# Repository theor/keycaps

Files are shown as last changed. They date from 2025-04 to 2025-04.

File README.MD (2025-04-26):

# Openscad labeled choc keycaps

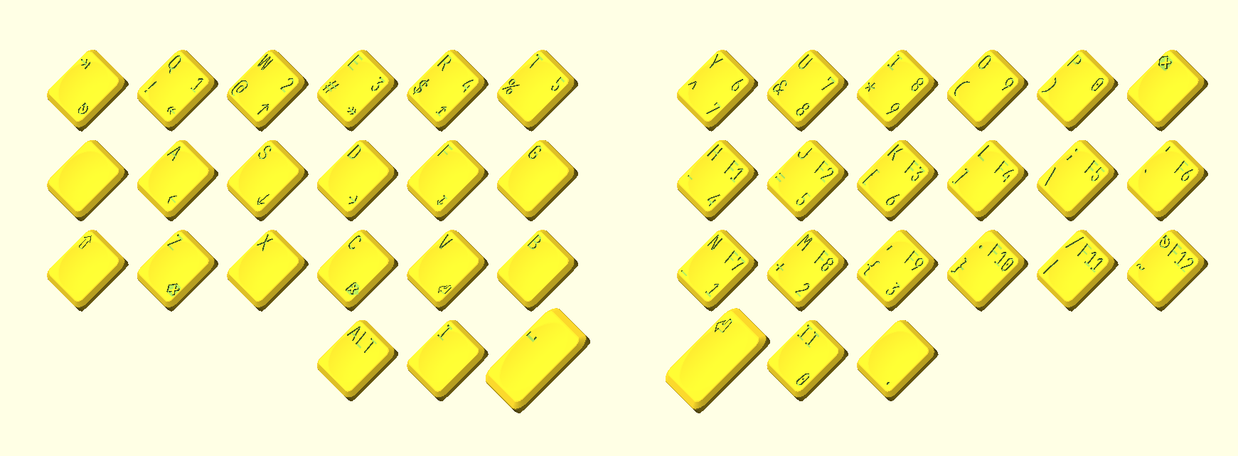
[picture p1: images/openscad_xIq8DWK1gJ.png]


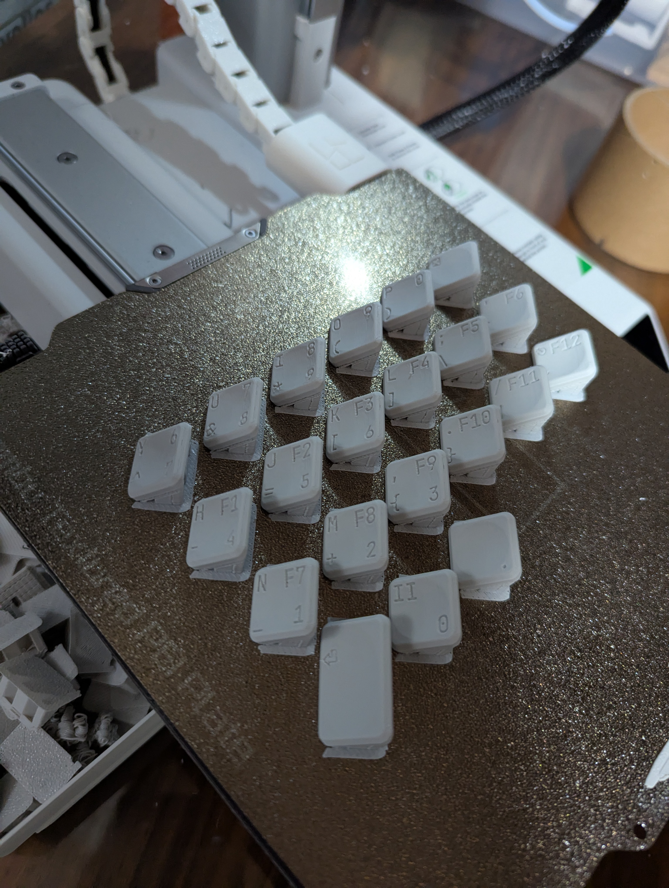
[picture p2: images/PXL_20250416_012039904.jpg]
result


> use the nightky build of openscad with the manifold backend, which is so much faster than the old CGAL backend

`keycaps.scad` takes pre-existing single keycap meshes (here `1u.stl` and `1.5u.stl`), a layout describing multiple keys (see `layout.cad`), then instantiate and label each key, and optionally adds a homing bump. it also add a bevel on the rear sides and rotates the key on it for 3d printing.

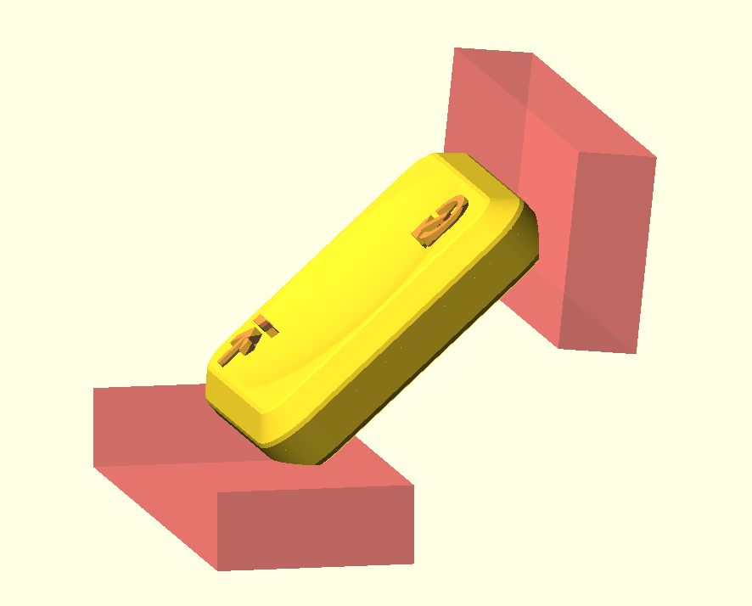
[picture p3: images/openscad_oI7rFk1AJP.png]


read the code for details on the input format and how the labeling works.

you might need to adjust the font - the code references `JetBrainsMono Nerd Font`. openscad has a Font List panel where you can test a font's support for specific characters.

I generated my layout.cad from the Vial layout  with a quick script.

# 3d Printing

In Orca slicer: I use **Snug supports** with a threshold of `42` degrees. it ensures the support will catch the entire back of the keycap withouyt needing to paint the support for each key:

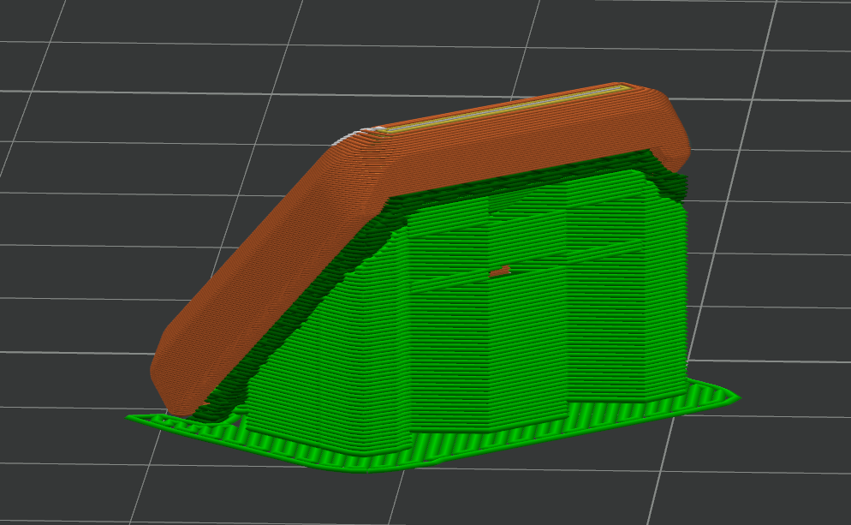
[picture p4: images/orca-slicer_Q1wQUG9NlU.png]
Support


Also disable the brim. I print in 0.08mm with a 0.4 nozzle, then do a VERY LIGHT sanding with 320 on the face and the bevel that was on the bed.

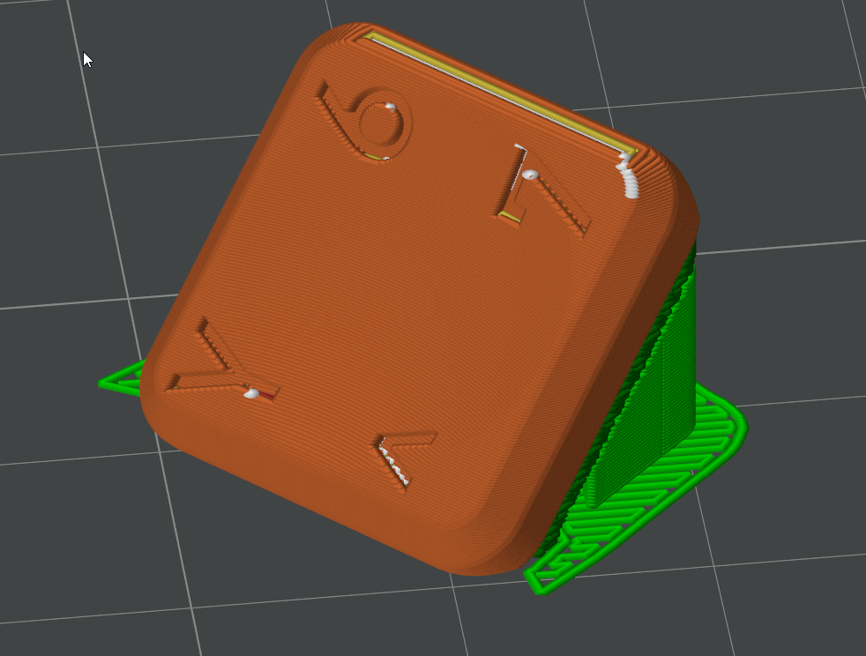
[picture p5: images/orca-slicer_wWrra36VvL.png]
front


# Keycaps credits

The keycap model itself is a reimplementation in Onshape of the great KEA caps : https://github.com/klouderone/KEA-choc-keycaps

Before KEA I used LPX, another great opensource keycap: https://github.com/levpopov/LPX

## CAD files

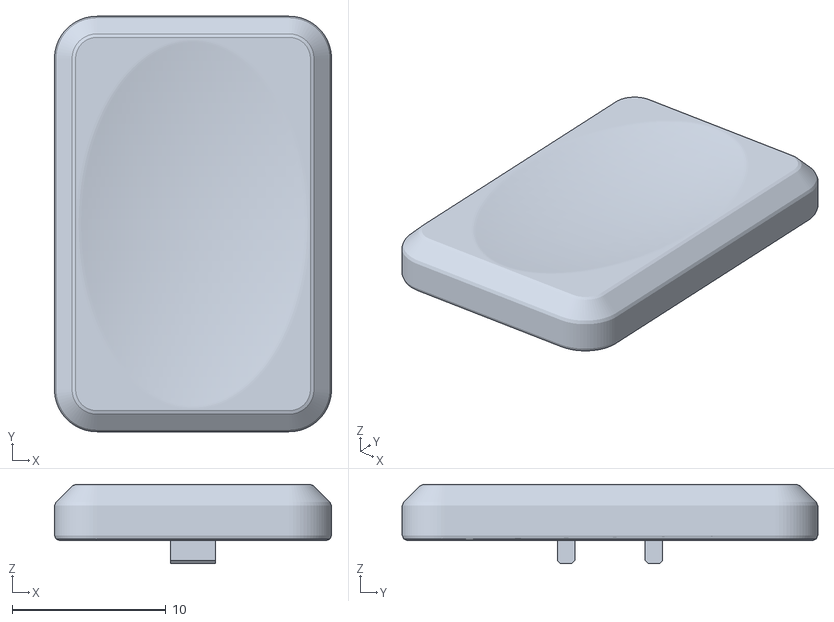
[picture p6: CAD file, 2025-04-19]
1.5u.stl
18.0 x 27.0 x 5.14

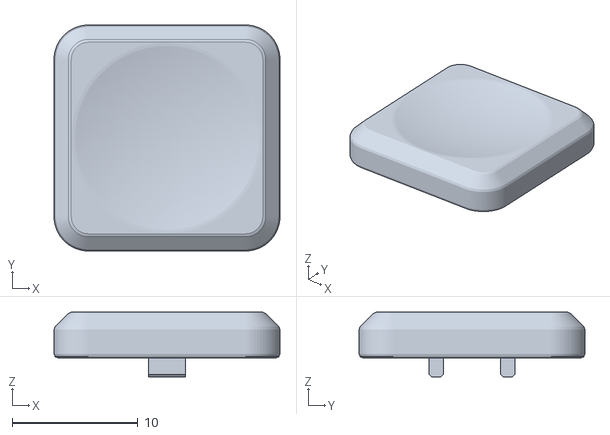
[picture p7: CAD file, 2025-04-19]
1u.stl
18.0 x 18.0 x 5.14

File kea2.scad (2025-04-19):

angled_preview = true;
preview_positions = false;

// not the actual dimensions of the keycap, remnant of earlier iterations
keycap_width = 18.0;
keycap_depth = 18.0;
keycap_height = 2.0;

font="JetBrainsMono Nerd Font:style=Regular";

// Margin from left and right of keycap to text
left_right_margin = keycap_width/2.5;
// Margin from top and bottom of keycap to text
top_bottom_margin = keycap_depth/4;
text_size = 4;
text_size_center = 8;
text_extrusion_height = 1.4;
label_offset_x = -0.1; // [-10:0.1:10]
label_offset_y = -1.8; // [-10:0.1:10]

fillet_angle=48;

text = ["Q", "1", "F2", "",""];
$fn=90;

// contains one variable
// keys = [
//   [[top left, top right, bottom left, bottom right, center], is 1.5U],
//   [["Q", "1", "!", "↞"], false],
//   [["␣", "", "", ""], true],
//   [["", "", "", "", "II"], false],
// ];
include <layout.scad>


module lpx(){
    rotate([0,0,90])
    import("./Key.stl",$fa=1,center=true);
}

module bottomFillet(){
    #translate([10,0,-1.4])
    rotate([0,fillet_angle,0])
    cube([4,20,10], center=true);
}

module keycap(text, is_thumb){
    rotate([0,$preview && !angled_preview ? 0 : -(90-fillet_angle),$preview ? 0 : -45])
    union(){
        scale([1  ,is_thumb ? 1.5 : 1   ,1])
        difference() {
            lpx();
            // both angled fillets. one is used to lay on the 3d printer bed
           bottomFillet();
           mirror([1,0,0])
           bottomFillet();
             
            // diff the surface and the label to get the part of the label above the surface, then translate that and remove it from the keycap surface
            translate([0,0,-.5])
            difference() {
                #labels(text);
                lpx();
            }
        }
    }
}
union(){
    // iterate on array, layout as a corne keyboard (split, 3x6+3 thumb keys each side)
    side = 6;
    half = len(keys)/2;
    for(k = [0:len(keys)-1]) {
        key = keys[k];
        if(len(key[0]) != 0){
            first = k < half ? 0 : half;
            x = (k-first)%side;
            p = [k < half
                ? x : (2*side - x), -floor((k-first) / side)] * keycap_width*1.3
               ;
            //    just a cube to help setting the layout
            if($preview && preview_positions){
                translate(p) cube(keycap_width);
            }
            else{
                // in preview mode, render only the first key
                if(!$preview || k == 0)
                    translate(p)
                        keycap(key[0], key[1]);
            }
        }
    }
}

module labels(text){
    union() {
        translate([label_offset_x, label_offset_y, keycap_height]) {
            sizes = [text_size,text_size,text_size,text_size,text_size_center];
            ox = [-1,1,-1,1,0.0];
            aligns = ["left", "right", "left", "right","center"];
            oy = [1,1,-1,-1,-0.5];
            for (i = [0:4]) {
                ll = 1;
                  // Move text down to cut into surface
                translate([ox[i]*left_right_margin*(ll), oy[i]*top_bottom_margin, -text_extrusion_height])
                    linear_extrude(height = text_extrusion_height * 2) {
                        text(text[i], font=font, size = sizes[i], halign = aligns[i], valign = "baseline");
                    }
            }
        }
    }
}

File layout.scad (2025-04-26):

/*[[topleft,topright,bottomleft,bottomright,center],is_1.5u,has_homing,[render_pos_x,render_pos_y]]*/
keys = [
  /*0*/[["⇥", "", "", "", ],false,false,[0.00,0.37]],
  /*1*/[["Q", "1", "", "↞", ],false,false,[1.00,0.37]],
  /*2*/[["W", "2", "", "↑", ],false,false,[2.00,0.12]],
  /*3*/[["E", "3", "", "↠", ],false,false,[3.00,0.00]],
  /*4*/[["R", "4", "", "⏎", ],false,false,[4.00,0.12]],
  /*5*/[["T", "5", "", "↥", ],false,false,[5.00,0.24]],
  /*6*/[["Y", "6", "", "7", ],false,false,[8.00,0.24]],
  /*7*/[["U", "7", "", "8", ],false,false,[9.00,0.12]],
  /*8*/[["I", "8", "", "9", ],false,false,[10.00,0.00]],
  /*9*/[["O", "9", "", "", ],false,false,[11.00,0.12]],
  /*10*/[["P", "0", "", "", ],false,false,[12.00,0.37]],
  /*11*/[["⌫", "", "", "", ],false,false,[13.00,0.37]],
  /*12*/[["", "", "", "", ],false,false,[0.00,1.37]],
  /*13*/[["A", "", "", "←", ],false,false,[1.00,1.37]],
  /*14*/[["S", "", "", "↓", ],false,false,[2.00,1.12]],
  /*15*/[["D", "", "", "→", ],false,false,[3.00,1.00]],
  /*16*/[["F", "", "", "⌫", ],false,true,[4.00,1.12]],
  /*17*/[["G", "", "", "↧", ],false,false,[5.00,1.24]],
  /*18*/[["H", "F1", "-", "4", ],false,false,[8.00,1.24]],
  /*19*/[["J", "F2", "=", "5", ],false,true,[9.00,1.12]],
  /*20*/[["K", "F3", "{", "6", ],false,false,[10.00,1.00]],
  /*21*/[["L", "F4", "}", "", ],false,false,[11.00,1.12]],
  /*22*/[[";", "F5", "\\", "", ],false,false,[12.00,1.37]],
  /*23*/[["'", "F6", "`", "", ],false,false,[13.00,1.37]],
  /*24*/[["⇧", "", "", "", ],false,false,[0.00,2.37]],
  /*25*/[["Z", "", "", "⌫", ],false,false,[1.00,2.37]],
  /*26*/[["X", "", "", "", ],false,false,[2.00,2.12]],
  /*27*/[["C", "", "", "⌦", ],false,false,[3.00,2.00]],
  /*28*/[["V", "", "", "", ],false,false,[4.00,2.12]],
  /*29*/[["B", "", "", "", ],false,false,[5.00,2.24]],
  /*30*/[["N", "F7", "-", "1", ],false,false,[8.00,2.24]],
  /*31*/[["M", "F8", "=", "2", ],false,false,[9.00,2.12]],
  /*32*/[[",", "F9", "{", "3", ],false,false,[10.00,2.00]],
  /*33*/[[".", "F10", "}", "", ],false,false,[11.00,2.12]],
  /*34*/[["/", "F11", "\\", "", ],false,false,[12.00,2.37]],
  /*35*/[["⎋", "F12", "`", "", ],false,false,[13.00,2.37]],
  /*36*/[["alt", "", "", "", ],false,false,[3.50,3.12]],
  /*37*/[["", "", "", "", ],false,false,[4.50,3.12]],
  /*38*/[["", "␣", "", "", ],true,false,[5.48,2.83]],
  /*39*/[["⏎", "", "", "", ],true,false,[7.52,2.83]],
  /*40*/[["", "", "", "0", ],false,false,[8.50,3.12]],
  /*41*/[["", "", "", ".", ],false,false,[9.50,3.12]],
];

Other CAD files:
keycaps.scad

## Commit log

2025-04-20 cleanup, fix 1.5u keys being scaled up instead of using dedicated models
    [1u.stl, keycaps.scad, layout.scad]
2025-04-26 use layout from json
    [keycaps.scad, layout.scad]
2025-04-26 add homing
    [keycaps.scad, layout.scad]
